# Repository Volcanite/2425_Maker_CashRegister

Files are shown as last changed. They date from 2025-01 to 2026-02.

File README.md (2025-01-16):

# 2425_Maker_CashRegister
Caisse enregistreuse à destination de la KFET. Elle permettrai de payer ses consommations et d'en avoir une traçabilité. On aurait également la possibilité de gérer les stocks et prévenir en cas de rupture. On pourrait également modifier les prix et les consommables proposés.

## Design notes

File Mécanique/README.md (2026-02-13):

# 2425_Maker_CashRegister

    En seconde année à l'ENSEA, un projet de conception d'une caisse enregistreuse ainsi que le module de paiement a été entreprit. Ce projet répond à une problématique de trésorerie présente dans l'école. En effet, durant chaque pause à la K-FET de l'école ou durant les événements, des produits sont mis en vente. Le personnel de l'école et les étudiants sont nombreux à payer en espèce et certains aimeraient payer en carte bancaise et cela engendre deux problèmes :
     - Les staffeurs doivent faire un bilan de la caisse réguliérement pour tenir les comptes ce qui est difficile dans certaines périodes.
     - Le paiement par carte bancaire implique soit un TPE qui impose des frais soit une application de paiement associatif sécurisée (Lyf, Lydia, HelloAsso, ...) qui ne sont pas le plus pratique au quotidien. 
     
     Des solutions ont été proposés mais cela demande la participation journalière d'étudiant. 
    
        Ainsi débute le projet de la caisse enregistreuse. Globalement on attend de celle-ci qu'elle puisse prendre des commandes et encaisser. Qu'elle puisse être reliée à plusieurs terminale de paiement permettant de traiter plusieurs clients à la fois en parallèle. Elle pourrait également aider les staffeurs sur le bilan de la caisse en liquidité et en paiement par carte ainsi qu'à faire un compte rendu des stocks. Evidemment tout cela serait sur base de donnée afin de pouvoir adapter l'interface à l'association et aux événements en cours. Enfin, une interface client serait mis à disposition afin de pouvoir créditer sa carte et suivre ses dernières transactions. Tout cela étant sauvegarder sur serveur avec backups en cas de problème.

## Décomposition du projet :
    Le projet se décompose en trois grandes parties : 
    - Mécanique : Modélisation et conception de la caisse à l'aide des outils présents à l'école. [lien vers Readme partie mécanique](./)
    - Electronique : Modélisation et conception d'une carte électronique pour le terminal de paiement permettant l'assemblage de différent module.
    - Software : Programmation embarquée de la caisse et du terminal de paiement. Réalisation d'une base de donnée hébergé sur serveur. Programmation d'une interface homme machine sur la caisse et d'un site utilisateur pour les clients et staffeurs.

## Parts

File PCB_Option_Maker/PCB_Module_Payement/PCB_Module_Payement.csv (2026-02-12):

Reference | Value | Datasheet | Footprint | Qty | DNP
BZ1 | Buzzer | ~ | Buzzer_Beeper:Buzzer_12x9.5RM7.6 | 1
C1 | 10u | ~ | Capacitor_SMD:C_0805_2012Metric | 1
C2,C4,C5,C13,C17,C19,C212 | 1u | https://www.we-online.com/components/products/datasheet/885012105006.pdf,~ | Capacitor_SMD:C_0402_1005Metric,Capacitor_SMD:C_0603_1608Metric | 7
C3 | 47u | ~ | Capacitor_SMD:C_0805_2012Metric | 1
C6 | 4u7 | ~ | Capacitor_SMD:C_0402_1005Metric | 1
C7,C10,C11,C12,C14,C16,C18,C211 | 100n | ~ | Capacitor_SMD:C_0402_1005Metric | 8
D1 | LED Blue | https://www.we-online.com/components/products/datasheet/150060RS55040.pdf | LED_SMD:LED_0603_1608Metric | 1
D2 | LED Amber | https://www.we-online.com/components/products/datasheet/150060AS55040.pdf | LED_SMD:LED_0603_1608Metric | 1
D3 | LED Yellow | https://www.we-online.com/components/products/datasheet/150060YS55040.pdf | LED_SMD:LED_0603_1608Metric | 1
D4 | LED_Blue | https://www.we-online.com/components/products/datasheet/150060BS55040.pdf | LED_SMD:LED_0603_1608Metric | 1
D5 | LED_Green | ~ | LED_SMD:LED_0603_1608Metric | 1
H1,H2,H3,H4 | MountingHole_Pad | ~ | MountingHole:MountingHole_2.7mm_M2.5_Pad | 4
J1 | Conn_02x07_Odd_Even | ~ | Connector_PinHeader_2.54mm:PinHeader_2x07_P2.54mm_Horizontal | 1
J3,J5 | Conn_01x08 | ~ | Connector_PinHeader_2.54mm:PinHeader_1x08_P2.54mm_Horizontal | 2
J4 | Conn_01x06 | ~ | Connector_PinHeader_2.54mm:PinHeader_1x06_P2.54mm_Horizontal | 1
J6 | Conn_01x04 | ~ | Connector_PinHeader_2.54mm:PinHeader_1x04_P2.54mm_Horizontal | 1
J7 | Conn_01x02 | ~ | Connector_JST:JST_XA_S02B-XASK-1_1x02_P2.50mm_Horizontal | 1
J8 | USB_C_Receptacle_USB2.0 | https://www.usb.org/sites/default/files/documents/usb_type-c.zip | Connector_USB:USB_C_Receptacle_HRO_TYPE-C-31-M-12 | 1
J9 | Conn_ST_STDC14 | https://www.st.com/content/ccc/resource/technical/document/user_manual/group1/99/49/91/b6/b2/3a/46/e5/DM00526767/files/DM00526767.pdf/jcr:content/translations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 | Connector_PinHeader_1.27mm:PinHeader_2x07_P1.27mm_Vertical_SMD | 1
J_Switch1 | Conn_01x03 | ~ | Connector_JST:JST_XA_S03B-XASK-1_1x03_P2.50mm_Horizontal | 1
L201 | 39n | ~ | Inductor_SMD:L_0805_2012Metric | 1
Q2 | MMBT2222A | https://assets.nexperia.com/documents/data-sheet/MMBT2222A.pdf | Package_TO_SOT_SMD:SOT-23 | 1
R1,R17,R19,R23 | 10K | ~ | Resistor_SMD:R_0402_1005Metric | 4
R2 | 168K | ~ | Resistor_SMD:R_0402_1005Metric | 1
R3 | 5k6 | ~ | Resistor_SMD:R_0402_1005Metric | 1
R4 | 49k9 | ~ | Resistor_SMD:R_0402_1005Metric | 1
R5,R6,R7,R9 | 10k | ~ | Resistor_SMD:R_0402_1005Metric | 4
R8 | 1K | ~ | Resistor_SMD:R_0402_1005Metric | 1
R10 | 68K | ~ | Resistor_SMD:R_0402_1005Metric | 1
R11,R12 | 5.1K | ~ | Resistor_SMD:R_0402_1005Metric | 2
R13,R14,R15 | 1k7 | ~ | Resistor_SMD:R_0402_1005Metric | 3
R20 | 510 | ~ | Resistor_SMD:R_0402_1005Metric | 1
R21 | R | ~ | Resistor_SMD:R_0402_1005Metric | 1
SW1,SW2,SW3 | SW_Push | ~ | Button_Switch_SMD:SW_Push_1P1T_NO_CK_KSC6xxJ | 3
U1,U5 | FSV330AF | https://www.farnell.com/datasheets/2572325.pdf | Schuttky:DO-214AD_ONS | 2
U2 | STM32G431CBUx | https://www.st.com/resource/en/datasheet/stm32g431cb.pdf | Package_DFN_QFN:QFN-48-1EP_7x7mm_P0.5mm_EP5.6x5.6mm | 1
U3 | 171013801 | https://www.we-online.com/en/components/products/datasheet/171013801.pdf | Wurth_regulator_171013801:Wurth_171013801 | 1
U4 | BU33SD5WG-TR | BU33SD5WG-TR | footprints:SSOP5_ROM | 1
U6 | USBLC6-2SC6 | https://www.st.com/resource/en/datasheet/usblc6-2.pdf | Package_TO_SOT_SMD:SOT-23-6 | 1

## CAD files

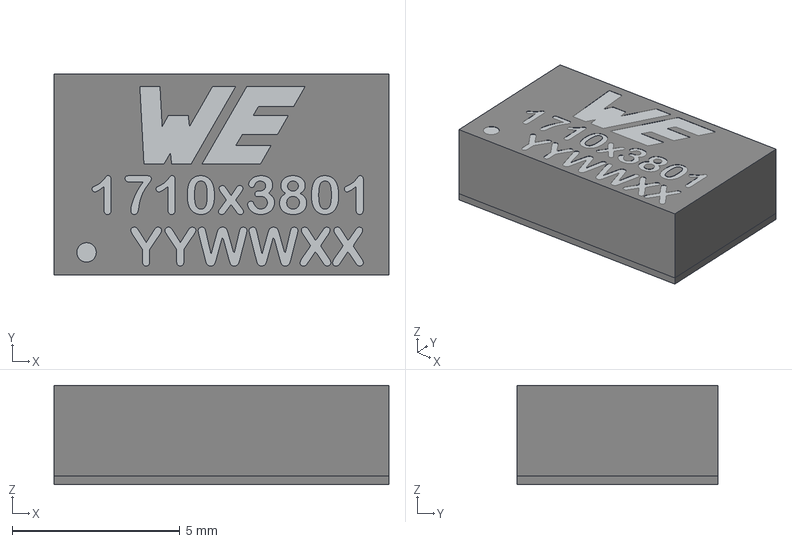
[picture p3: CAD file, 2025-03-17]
PCB_Option_Maker/PCB_Module_Payement/Wurth_171013801.stp
10.0 x 6.00 x 2.97 mm
Base
Pads

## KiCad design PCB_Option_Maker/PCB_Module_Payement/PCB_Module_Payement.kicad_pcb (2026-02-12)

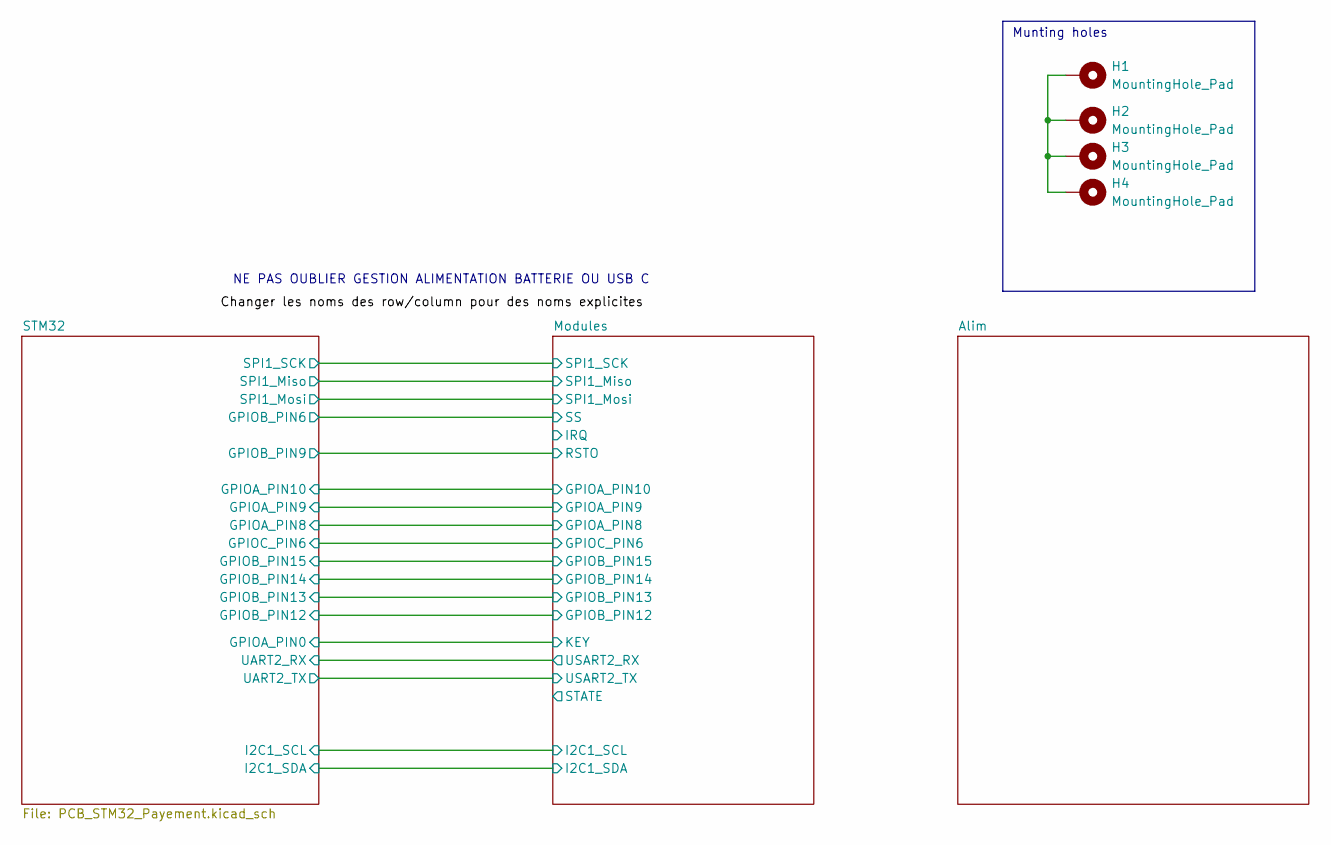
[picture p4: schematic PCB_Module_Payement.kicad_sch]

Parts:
H1, H2, H3, H4: MountingHole_Pad; MountingHole_2.7mm_M2.5_Pad

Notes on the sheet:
Munting holes
NE PAS OUBLIER GESTION ALIMENTATION BATTERIE OU USB C

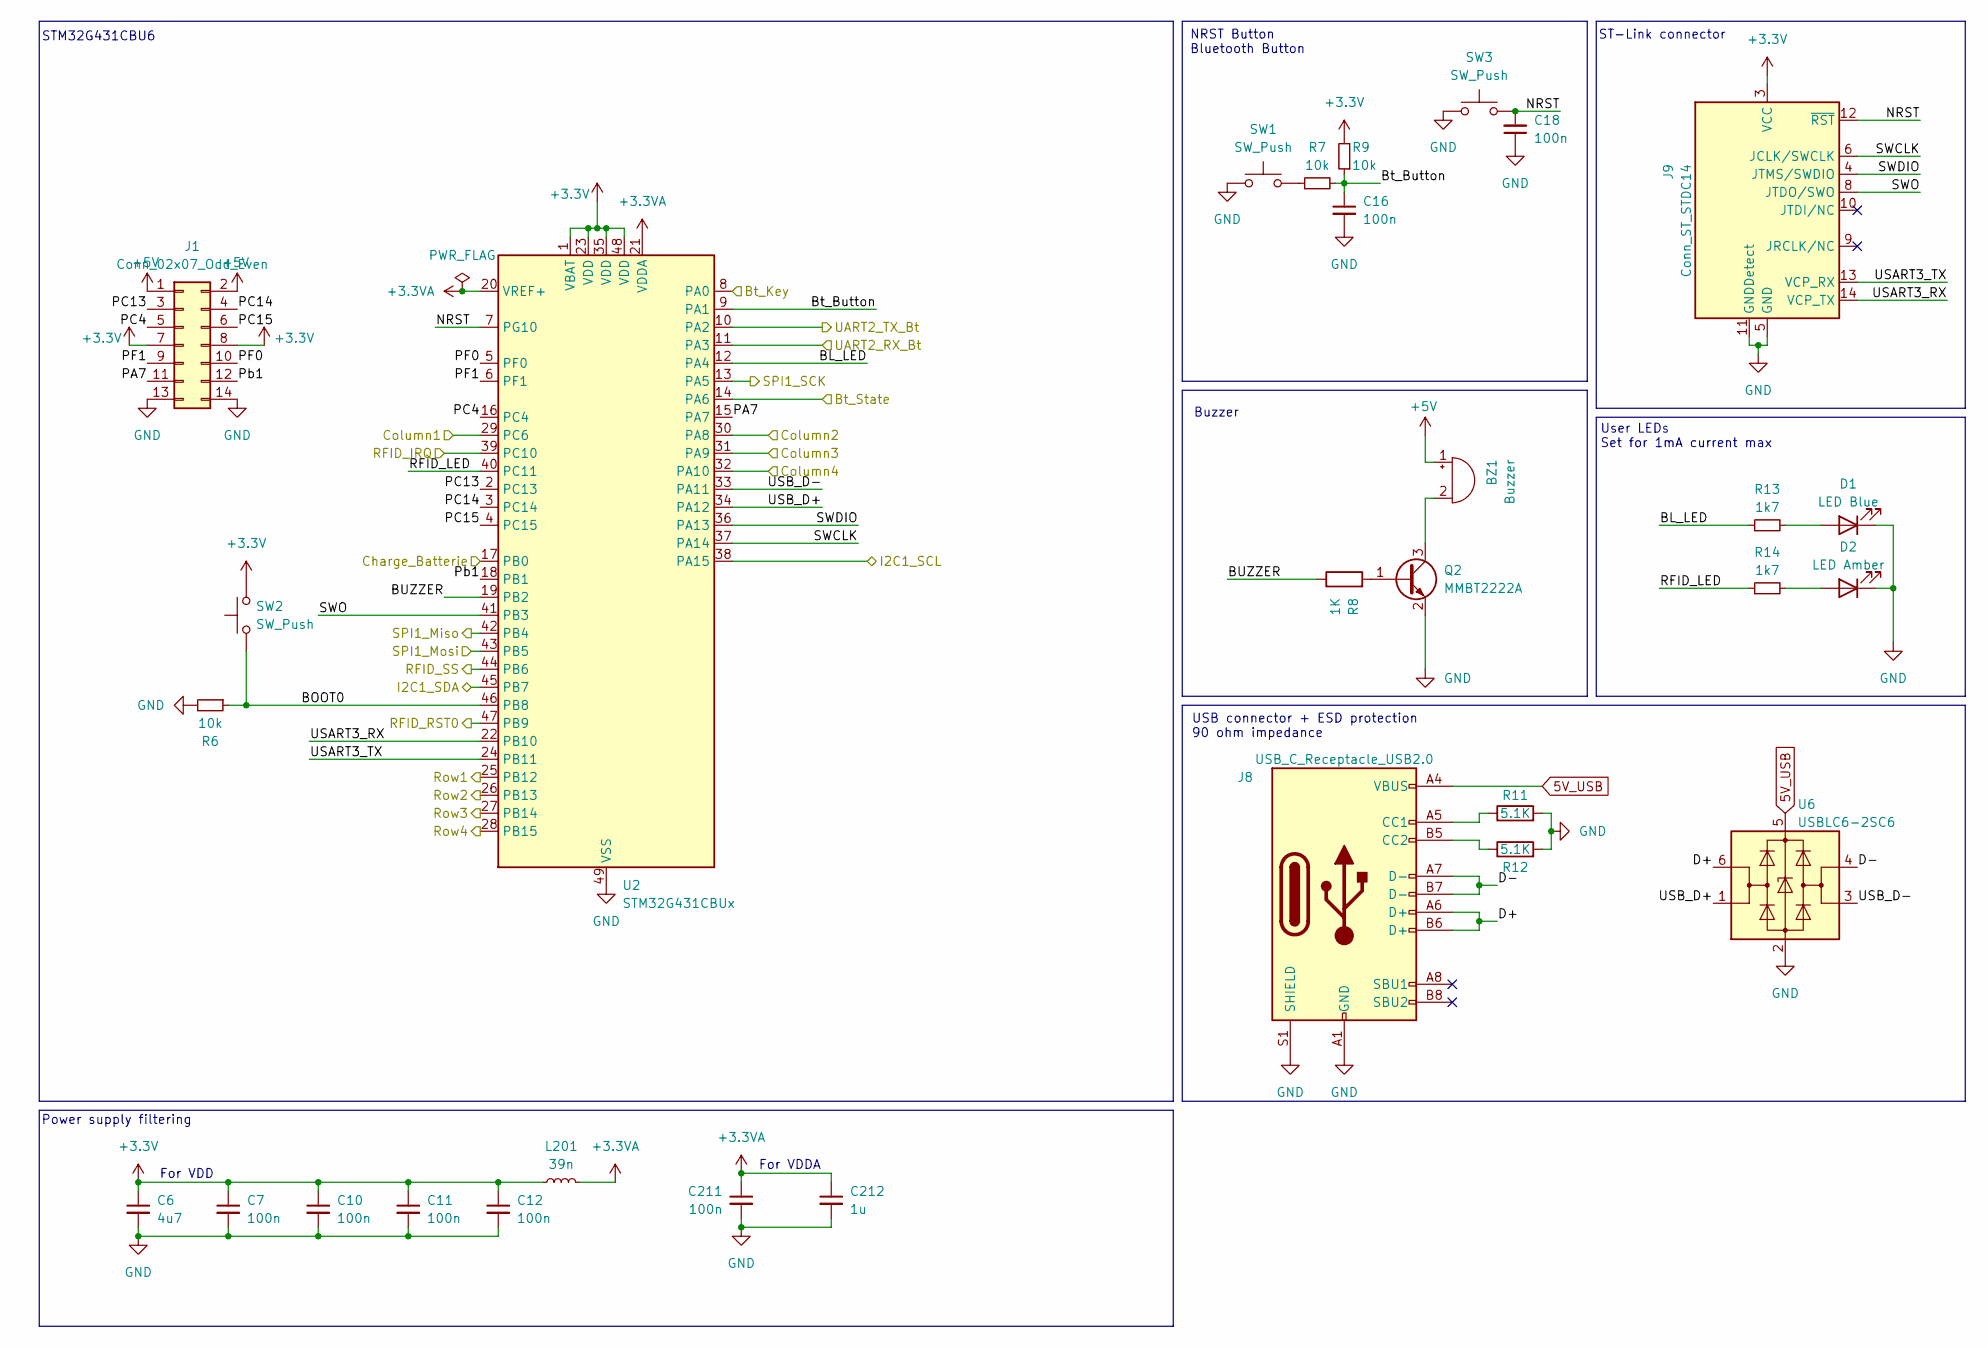
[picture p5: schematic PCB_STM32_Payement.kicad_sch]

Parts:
BZ1: Buzzer; Buzzer_12x9.5RM7.6
C6: 4u7; C_0402_1005Metric
C7, C10, C11, C12, C16, C18, C211: 100n; C_0402_1005Metric
C212: 1u; C_0603_1608Metric; MPN 885012105006
D1: LED Blue; LED_0603_1608Metric; MPN 150060RS55040
D2: LED Amber; LED_0603_1608Metric; MPN 150060AS55040
J1: Conn_02x07_Odd_Even; PinHeader_2x07_P2.54mm_Horizontal
J8: USB_C_Receptacle_USB2.0; USB_C_Receptacle_HRO_TYPE-C-31-M-12
J9: Conn_ST_STDC14; PinHeader_2x07_P1.27mm_Vertical_SMD
L201: 39n; L_0805_2012Metric
Q2: MMBT2222A; SOT-23
R6, R7, R9: 10k; R_0402_1005Metric
R8: 1K; R_0402_1005Metric
R11, R12: 5.1K; R_0402_1005Metric
R13, R14: 1k7; R_0402_1005Metric
SW1, SW2, SW3: SW_Push; SW_Push_1P1T_NO_CK_KSC6xxJ
U2: STM32G431CBUx; QFN-48-1EP_7x7mm_P0.5mm_EP5.6x5.6mm
U6: USBLC6-2SC6; SOT-23-6

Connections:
5V_USB: J8.A4 (VBUS), J8.A9 (VBUS), J8.B4 (VBUS), J8.B9 (VBUS), U6.5 (VBUS); also elsewhere on the board
+3.3V: C6.1, C7.1, C10.1, C11.1, C12.1, J1.7, J1.8, J9.3 (VCC), L201.1, R9.2, SW2.2, U2.1 (VBAT), U2.23 (VDD), U2.35 (VDD), U2.48 (VDD); also elsewhere on the board
+3.3VA: C211.1, C212.1, L201.2, U2.20 (VREF+), U2.21 (VDDA)
+5V: BZ1.1 (+), J1.1, J1.2; also elsewhere on the board
/Alim/Charge_Batterie: U2.17 (PB0); also elsewhere on the board
/Modules/Bt_RXD: U2.10 (PA2); also elsewhere on the board
/Modules/Bt_TXD: U2.11 (PA3); also elsewhere on the board
/Modules/Culomn1: U2.29 (PC6); also elsewhere on the board
/Modules/Culomn2: U2.30 (PA8); also elsewhere on the board
/Modules/Culomn3: U2.31 (PA9); also elsewhere on the board
/Modules/Culomn4: U2.32 (PA10); also elsewhere on the board
/Modules/I2C1_SCL: U2.45 (PB7); also elsewhere on the board
/Modules/I2C1_SDA: U2.38 (PA15); also elsewhere on the board
/Modules/IRQ: U2.39 (PC10); also elsewhere on the board
/Modules/KEY: U2.8 (PA0); also elsewhere on the board
/Modules/R0W1: U2.25 (PB12); also elsewhere on the board
/Modules/ROW2: U2.26 (PB13); also elsewhere on the board
/Modules/ROW3: U2.27 (PB14); also elsewhere on the board
/Modules/ROW4: U2.28 (PB15); also elsewhere on the board
/Modules/RSTO: U2.47 (PB9); also elsewhere on the board
/Modules/SPI1_Miso: U2.42 (PB4); also elsewhere on the board
/Modules/SPI1_Mosi: U2.43 (PB5); also elsewhere on the board
/Modules/SPI1_SCK: U2.13 (PA5); also elsewhere on the board
/Modules/SS: U2.44 (PB6); also elsewhere on the board
/Modules/STATE: U2.14 (PA6); also elsewhere on the board
/STM32/BL_LED: R13.1, U2.12 (PA4)
/STM32/BOOT0: R6.1, SW2.1, U2.46 (PB8)
/STM32/BUZZER: R8.1, U2.19 (PB2)
/STM32/Bt_Button: C16.1, R7.2, R9.1, U2.9 (PA1)
/STM32/D+: J8.A6 (D+), J8.B6 (D+), U6.6 (I/O1)
/STM32/D-: J8.A7 (D-), J8.B7 (D-), U6.4 (I/O2)
/STM32/NRST: C18.2, J9.12 (~RST), SW3.2, U2.7 (PG10)
/STM32/PA7: J1.11, U2.15 (PA7)
/STM32/PC4: J1.5, U2.16 (PC4)
/STM32/PC13: J1.3, U2.2 (PC13)
/STM32/PC14: J1.4, U2.3 (PC14)
/STM32/PC15: J1.6, U2.4 (PC15)
/STM32/PF0: J1.10, U2.5 (PF0)
/STM32/PF1: J1.9, U2.6 (PF1)
/STM32/Pb1: J1.12, U2.18 (PB1)
/STM32/RFID_LED: R14.1, U2.40 (PC11)
/STM32/SWCLK: J9.6 (JCLK/SWCLK), U2.37 (PA14)
/STM32/SWDIO: J9.4 (JTMS/SWDIO), U2.36 (PA13)
/STM32/SWO: J9.8 (JTDO/SWO), U2.41 (PB3)
/STM32/USART3_RX: J9.14 (VCP_TX), U2.22 (PB10)
/STM32/USART3_TX: J9.13 (VCP_RX), U2.24 (PB11)
/STM32/USB_D+: U2.34 (PA12), U6.1 (I/O1)
/STM32/USB_D-: U2.33 (PA11), U6.3 (I/O2)
unnamed: BZ1.2 (-), Q2.3 (C)
unnamed: D1.2 (A), R13.2
unnamed: D2.2 (A), R14.2
unnamed: J8.A5 (CC1), R11.1
unnamed: J8.B5 (CC2), R12.1
unnamed: Q2.1 (B), R8.2
unnamed: R7.1, SW1.2

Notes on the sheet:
ST-Link connector
User LEDs Set for 1mA current max
NRST Button Bluetooth Button
For VDDA
For VDD
Power supply filtering
Buzzer
USB connector + ESD protection 90 ohm impedance
STM32G431CBU6

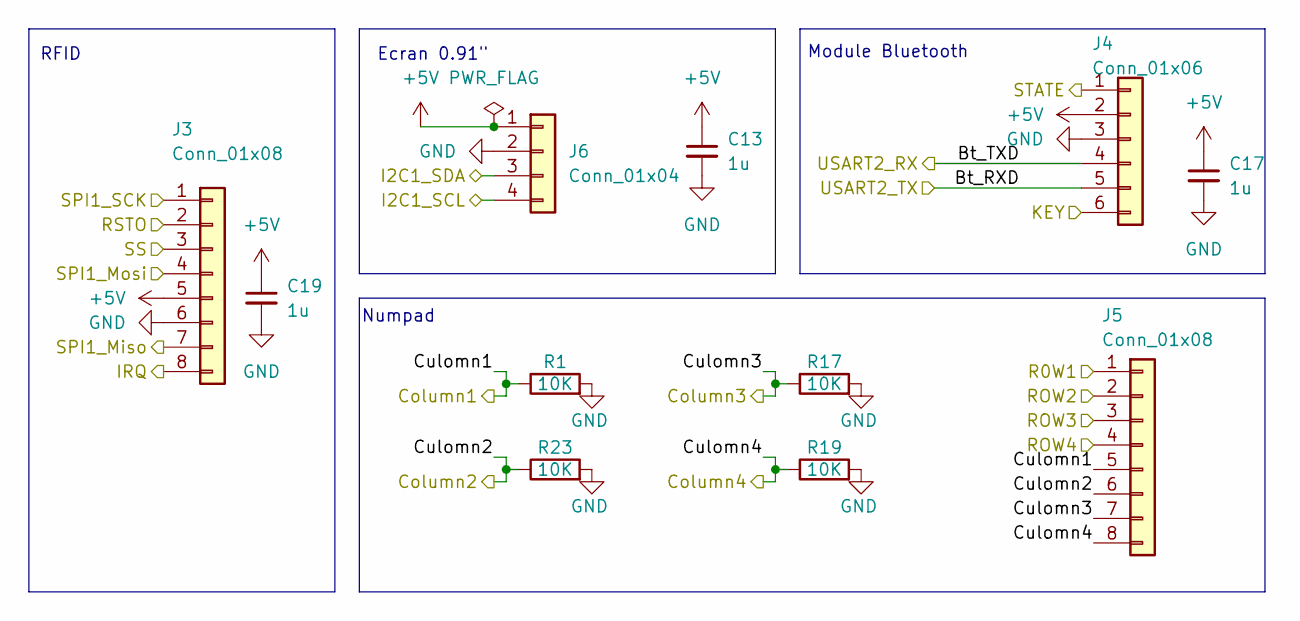
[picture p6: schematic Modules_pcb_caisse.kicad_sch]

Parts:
C13, C17, C19: 1u; C_0402_1005Metric
J3, J5: Conn_01x08; PinHeader_1x08_P2.54mm_Horizontal
J4: Conn_01x06; PinHeader_1x06_P2.54mm_Horizontal
J6: Conn_01x04; PinHeader_1x04_P2.54mm_Horizontal
R1, R17, R19, R23: 10K; R_0402_1005Metric

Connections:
+5V: C13.1, C17.1, C19.1, J3.5, J4.2, J6.1; also elsewhere on the board
/Modules/Bt_RXD: J4.5; also elsewhere on the board
/Modules/Bt_TXD: J4.4; also elsewhere on the board
/Modules/Culomn1: J5.5, R1.1; also elsewhere on the board
/Modules/Culomn2: J5.6, R23.1; also elsewhere on the board
/Modules/Culomn3: J5.7, R17.1; also elsewhere on the board
/Modules/Culomn4: J5.8, R19.1; also elsewhere on the board
/Modules/I2C1_SCL: J6.4; also elsewhere on the board
/Modules/I2C1_SDA: J6.3; also elsewhere on the board
/Modules/IRQ: J3.8; also elsewhere on the board
/Modules/KEY: J4.6; also elsewhere on the board
/Modules/R0W1: J5.1; also elsewhere on the board
/Modules/ROW2: J5.2; also elsewhere on the board
/Modules/ROW3: J5.3; also elsewhere on the board
/Modules/ROW4: J5.4; also elsewhere on the board
/Modules/RSTO: J3.2; also elsewhere on the board
/Modules/SPI1_Miso: J3.7; also elsewhere on the board
/Modules/SPI1_Mosi: J3.4; also elsewhere on the board
/Modules/SPI1_SCK: J3.1; also elsewhere on the board
/Modules/SS: J3.3; also elsewhere on the board
/Modules/STATE: J4.1; also elsewhere on the board

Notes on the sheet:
Numpad
RFID
Module Bluetooth
Ecran 0.91"

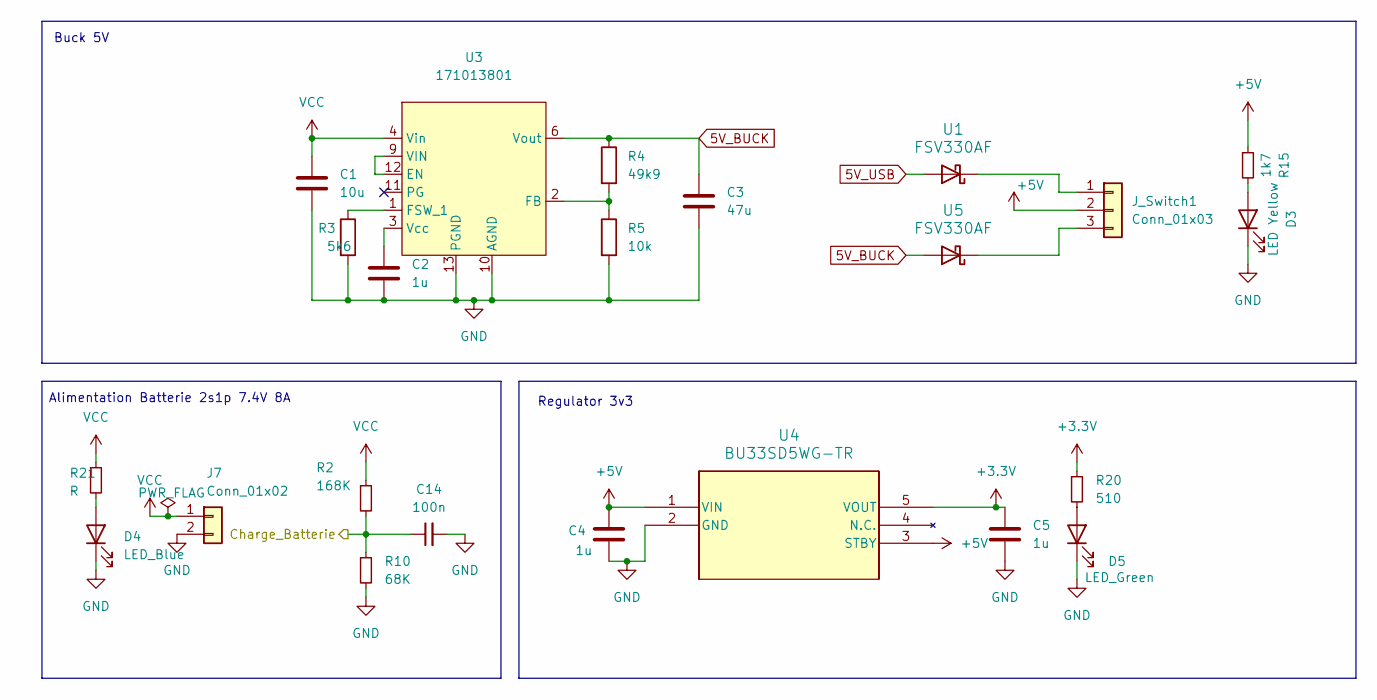
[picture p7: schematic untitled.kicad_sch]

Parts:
C1: 10u; C_0805_2012Metric
C2, C4, C5: 1u; C_0402_1005Metric
C3: 47u; C_0805_2012Metric
C14: 100n; C_0402_1005Metric
D3: LED Yellow; LED_0603_1608Metric; MPN 150060YS55040
D4: LED_Blue; LED_0603_1608Metric
D5: LED_Green; LED_0603_1608Metric
J7: Conn_01x02; JST_XA_S02B-XASK-1_1x02_P2.50mm_Horizontal
J_Switch1: Conn_01x03; JST_XA_S03B-XASK-1_1x03_P2.50mm_Horizontal
R2: 168K; R_0402_1005Metric
R3: 5k6; R_0402_1005Metric
R4: 49k9; R_0402_1005Metric
R5: 10k; R_0402_1005Metric
R10: 68K; R_0402_1005Metric
R15: 1k7; R_0402_1005Metric
R20: 510; R_0402_1005Metric
R21: R; R_0402_1005Metric
U1, U5: FSV330AF; DO-214AD_ONS; MPN FSV330AF
U3: 171013801; Wurth_171013801; MPN 171013801
U4: BU33SD5WG-TR; SSOP5_ROM

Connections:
5V_BUCK: C3.1, R4.1, U3.6 (Vout), U3.7 (Vout), U5.2 (A)
5V_USB: U1.2 (A); also elsewhere on the board
+3.3V: C5.2, R20.1, U4.5 (VOUT); also elsewhere on the board
+5V: C4.1, J_Switch1.2, R15.1, U4.1 (VIN), U4.3 (STBY); also elsewhere on the board
/Alim/Charge_Batterie: C14.1, R2.2, R10.1; also elsewhere on the board
unnamed: D3.2 (A), R15.2
unnamed: D4.2 (A), R21.2
unnamed: D5.2 (A), R20.2
unnamed: J_Switch1.1, U1.1 (K)
unnamed: J_Switch1.3, U5.1 (K)
unnamed: U3.9 (VIN), U3.12 (EN)
unnamed: R4.2, R5.1, U3.2 (FB)
unnamed: R3.1, U3.1 (FSW_1)
unnamed: C2.1, U3.3 (Vcc)
VCC: C1.1, J7.1, R2.1, R21.1, U3.4 (Vin), U3.5 (Vin)

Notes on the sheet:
Alimentation Batterie 2s1p 7.4V 8A
Regulator 3v3
Buck 5V

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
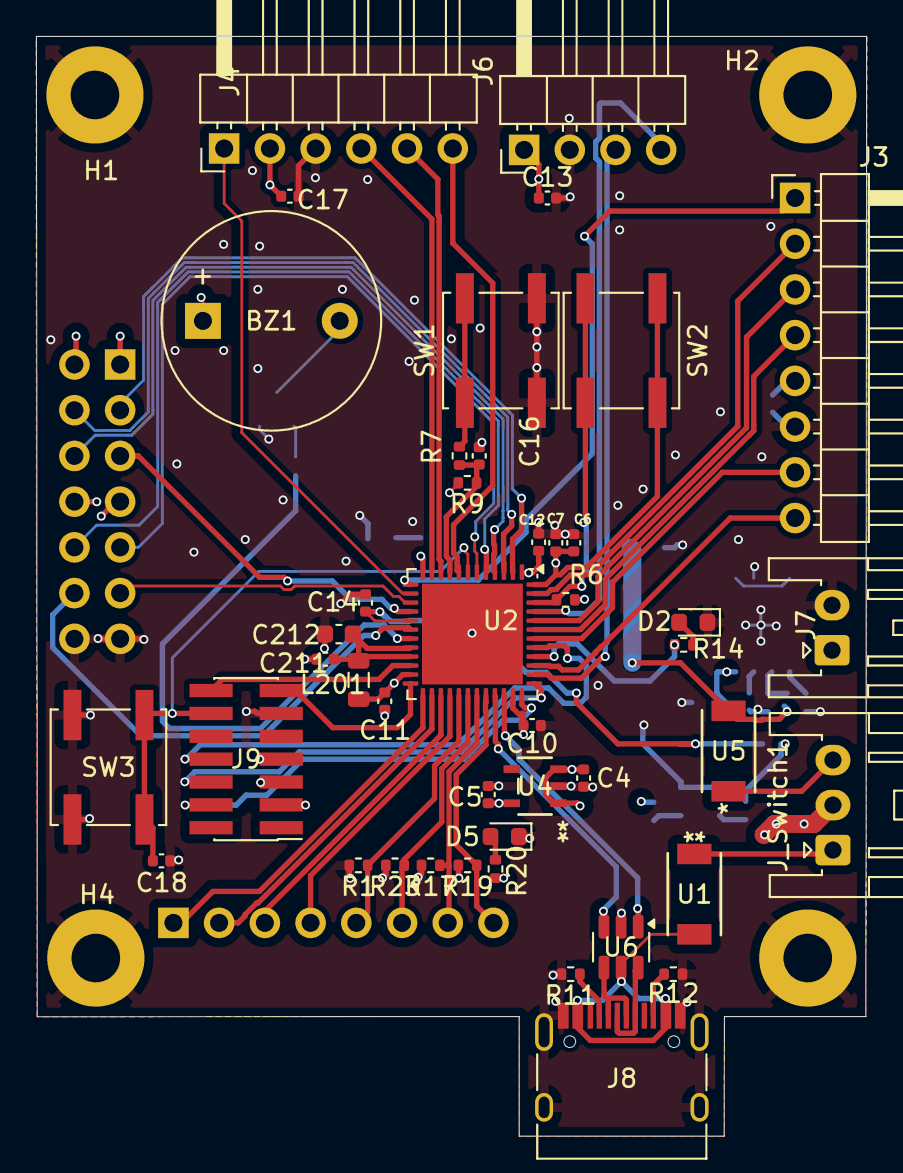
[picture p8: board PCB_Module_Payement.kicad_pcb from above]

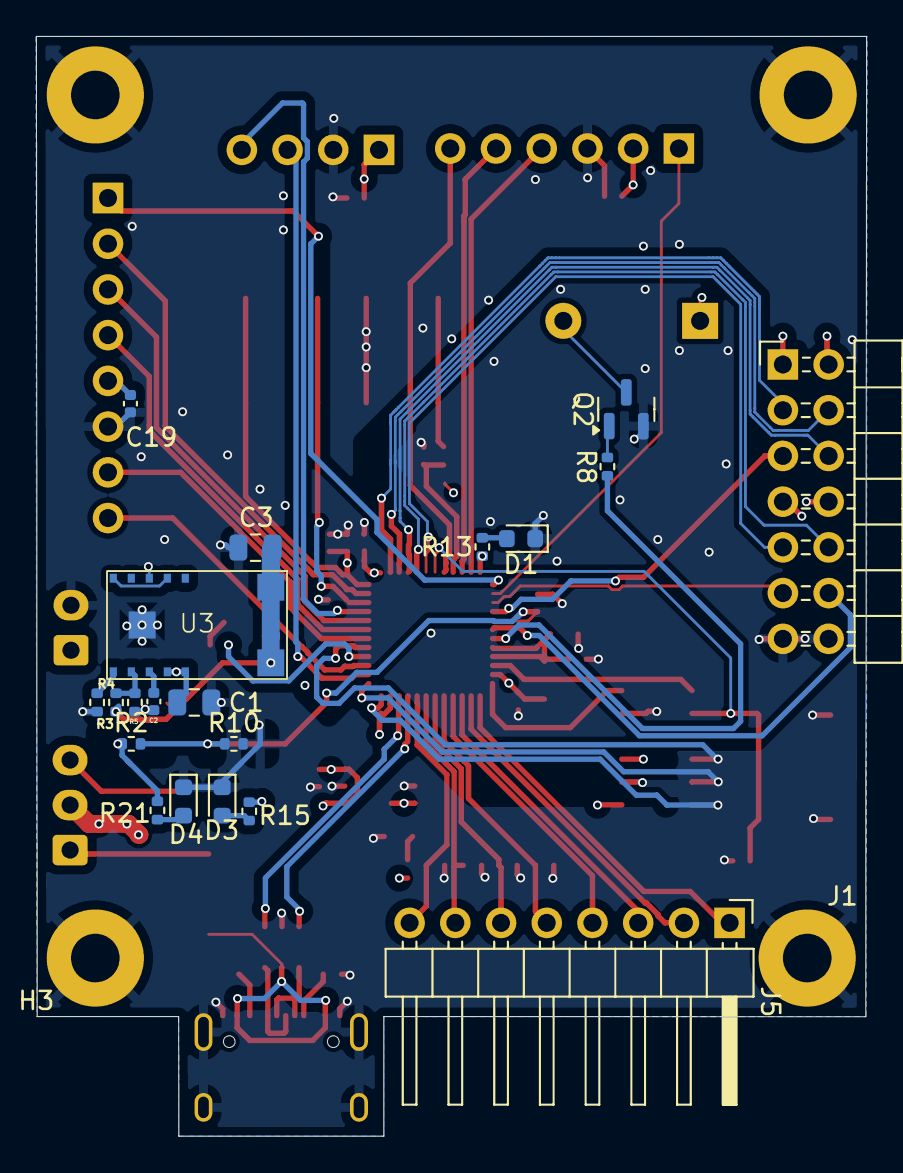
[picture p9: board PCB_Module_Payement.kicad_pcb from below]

Board: 4 copper layers, 46.1 x 61.1 mm, 68 parts (20 on the bottom side), 67 nets.

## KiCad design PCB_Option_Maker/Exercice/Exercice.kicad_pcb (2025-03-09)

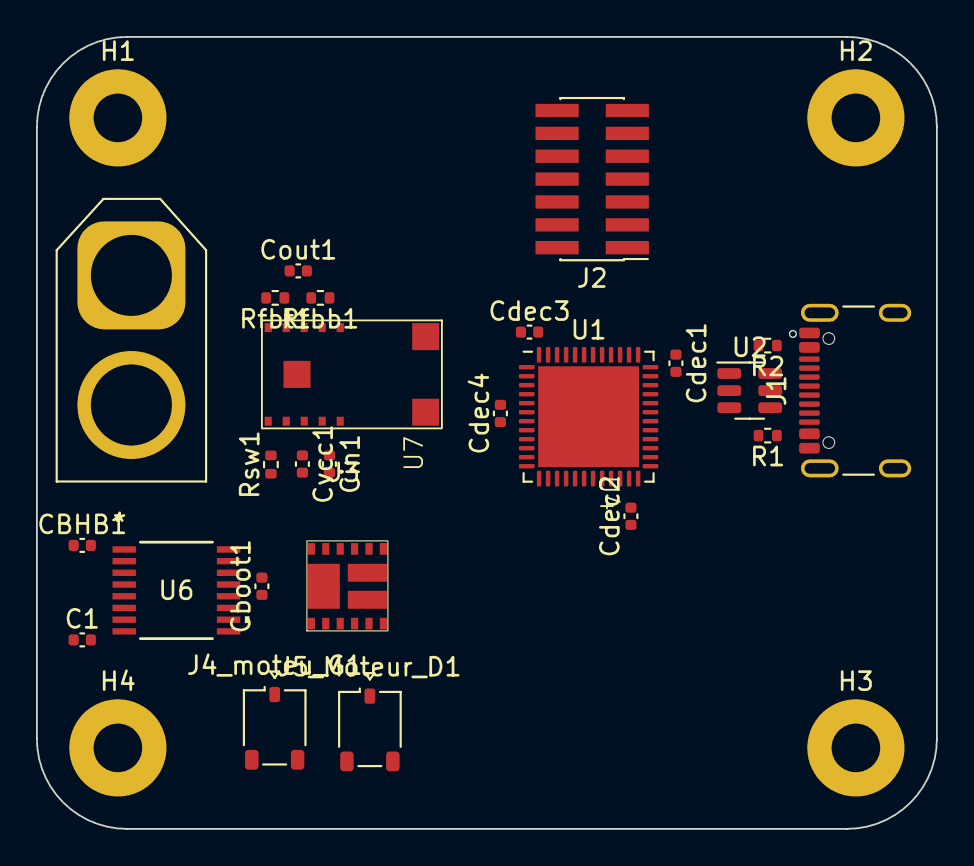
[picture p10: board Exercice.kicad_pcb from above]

Board: 4 copper layers, 50.0 x 44.0 mm, 29 parts (0 on the bottom side), 28 nets, no tracks yet.

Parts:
C1: 0.2u; C_0402_1005Metric
CBHB1: 0.2u; C_0402_1005Metric
Cboot1: 2u; C_0402_1005Metric
Cdec1: 4u7; C_0402_1005Metric
Cdec2, Cdec3, Cdec4: 100n; C_0402_1005Metric
Cin1: 10u; C_0402_1005Metric
Cout1: 47u; C_0402_1005Metric
Cvcc1: 1u; C_0402_1005Metric
H1, H2, H3, H4: MountingHole_Pad; MountingHole_2.7mm_M2.5_Pad
J1: USB_C_Receptacle_USB2.0_16P; USB_C_Receptacle_GCT_USB4105-xx-A_16P_TopMnt_Horizontal
J2: Conn_02x07_Odd_Even; PinHeader_2x07_P1.27mm_Vertical_SMD
J3: Conn_01x02; AMASS_XT60-F_1x02_P7.20mm_Vertical
J4_moteu_G1, J5_Moteur_D1: Conn_01x01; JST_ACH_BM01B-ACHSS-A-GAN-ETF_1x01-1MP_P1.20mm_Vertical
R1, R2: 5.1K; R_0402_1005Metric
Rfbb1: 137K; R_0402_1005Metric
Rfbt1: 402K; R_0402_1005Metric
Rsw1: 5.6K; R_0402_1005Metric
U1: STM32G431CBUx; QFN-48-1EP_7x7mm_P0.5mm_EP5.6x5.6mm
U2: USBLC6-2SC6; SOT-23-6
U4: Wurth_171013801
U6: MIC4606-2YTS-TR; TSSOP16_TS_MCH_MIS
U7: NMOS_FDMQ86530L

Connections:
/AHO: U6.9 (AHO), U7.12 (G4)
/ALO: U6.11 (ALO), U7.9 (G3)
/APWM: U1.13 (PA5), U6.6 (APWM)
/BHO: U6.16 (BHO), U7.1 (G1)
/BLO: U6.14 (BLO), U7.4 (G2)
/BPWM: U1.14 (PA6), U6.3 (BPWM)
/D+: J1.A6 (D+), J1.B6 (D+), U2.6 (I/O1)
/D-: J1.A7 (D-), J1.B7 (D-), U2.4 (I/O2)
/GND: Cin1.2, Cout1.2, Cvcc1.2, Rfbb1.1, Rsw1.1, U4.10 (AGND), U4.13 (PGND)
/NRST: Cdec4.1, J2.12, U1.7 (PG10)
/SWDCK: J2.6, U1.37 (PA14)
/SWDIO: J2.4, U1.36 (PA13)
/USB_DM: U1.33 (PA11), U2.3 (I/O2)
/USB_DP: U1.34 (PA12), U2.1 (I/O1)
/Usart2_Rx: J2.13, U1.11 (PA3)
/Usart2_Tx: J2.14, U1.10 (PA2)
/V_USB: J1.A4 (VBUS), J1.A9 (VBUS), J1.B4 (VBUS), J1.B9 (VBUS), U2.5 (VBUS)
/Vout_3V3: Cdec1.2, Cdec2.2, Cdec3.2, Cout1.1, J2.3, Rfbt1.2, U1.1 (VBAT), U1.20 (VREF+), U1.21 (VDDA), U1.23 (VDD), U1.35 (VDD), U1.48 (VDD), U4.6 (Vout), U4.7 (Vout)
ISO_GND: C1.1, CBHB1.1, Cboot1.2, Cdec1.1, Cdec2.1, Cdec3.1, Cdec4.2, H1.1, H2.1, H3.1, H4.1, J1.A1 (GND), J1.A12 (GND), J1.B1 (GND), J1.B12 (GND), J1.S1 (SHIELD), J2.5, J2.7, J2.11, J3.1, J4_moteu_G1.1, J5_Moteur_D1.1, R1.2, R2.2, U1.49 (VSS), U2.2 (GND), U6.10 (AHS), U6.15 (BHS), U7.3 (S1/D2), U7.5 (S2), U7.6 (S2), U7.7 (S3), U7.8 (S3), U7.10 (D3/S4)
unnamed: J1.A5 (CC1), R1.1
unnamed: J1.B5 (CC2), R2.1
unnamed: U4.9 (VIN), U4.12 (EN)
unnamed: Rfbb1.2, Rfbt1.1, U4.2 (FB)
unnamed: Rsw1.2, U4.1 (FSW_1)
unnamed: Cvcc1.1, U4.3 (Vcc)
unnamed: C1.2, U6.8 (AHB)
unnamed: CBHB1.2, U6.1 (BHB)
Vin_15V: Cboot1.1, Cin1.1, J3.2, U4.4 (Vin), U4.5 (Vin), U6.2 (EN), U6.12 (VDD), U7.2 (D1/D4), U7.11 (D1/D4)

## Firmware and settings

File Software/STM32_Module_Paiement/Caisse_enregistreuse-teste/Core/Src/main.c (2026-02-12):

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
/* Includes ------------------------------------------------------------------*/
#include "main.h"
#include "adc.h"
#include "i2c.h"
#include "tim.h"
#include "usart.h"
#include "gpio.h"

/* USER CODE BEGIN Includes */
#include "ssd1306.h"
#include "Screen.h"
/* USER CODE END Includes */


void SystemClock_Config(void);
/* USER CODE BEGIN 0 */
#ifdef __GNUC__
#define PUTCHAR_PROTOTYPE int __io_putchar(int ch)
#else
#define PUTCHAR_PROTOYPE int fputc(int ch, FILE *f)
#endif

PUTCHAR_PROTOTYPE
{
	HAL_UART_Transmit(&huart2, (uint8_t *)&ch, 1, HAL_MAX_DELAY);
	return ch;
}


/* USER CODE END 0 */

/**
 * @brief  The application entry point.
 * @retval int
 */
int main(void)
{

	/* MCU Configuration--------------------------------------------------------*/

	/* Reset of all peripherals, Initializes the Flash interface and the Systick. */
	HAL_Init();

	/* Configure the system clock */
	SystemClock_Config();

	/* Initialize all configured peripherals */
	MX_GPIO_Init();
	MX_USART2_UART_Init();
	MX_TIM2_Init();
	MX_UART5_Init();
	MX_I2C1_Init();
	MX_I2C2_Init();
	MX_ADC1_Init();
	/* USER CODE BEGIN 2 */
	printf("Hello!\r\n");
	RFID_init();
	RFID_Get_UID_Card();
	Initialisation();
	HAL_Delay(1500);
	Default_Use();
	/*
	RFID_init();
	RFID_Get_UID_Card();
	RFID_Get_Block_Information();*/ // RFID lire carte
	/* USER CODE END 2 */

	/* Infinite loop */
	/* USER CODE BEGIN WHILE */
	while (1)
	{

		/* USER CODE END WHILE */

		/* USER CODE BEGIN 3 */



	}


	/* USER CODE END 3 */
}

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
/* USER CODE BEGIN 4 */
void HAL_GPIO_EXTI_Callback(uint16_t GPIO_Pin){
	// Déterminer quelle colonne a déclenché

}

void HAL_UART_RxCpltCallback(UART_HandleTypeDef *huart) {
	/*if (huart->Instance == UART5) {
		HAL_GPIO_TogglePin(green_GPIO_Port, green_Pin);  // Toggle la LED pour indiquer la réception

		// Ajouter un caractère de fin pour afficher les données
		buffer[sizeof(buffer) - 1] = '\0';

		// Afficher les données reçues
		printf("Reçu : %s\n", buffer);

		// Écho des données reçues
		HAL_UART_Transmit(&huart5, buffer, strlen((char*)buffer), HAL_MAX_DELAY);

		// Réactiver la réception
		HAL_UART_Receive_IT(&huart5, buffer, sizeof(buffer));
	}*/
}
/* USER CODE END 4 */
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


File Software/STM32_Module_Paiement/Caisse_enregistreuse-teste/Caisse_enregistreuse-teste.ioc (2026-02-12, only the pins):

Mcu.UserName=STM32L476RGTx
PA0.Signal=S_TIM2_CH1
PA10.GPIO_Label=Col4
PA10.Signal=GPIO_Output
PA2.GPIO_Label=USART_TX
PA2.Signal=USART2_TX
PA3.GPIO_Label=USART_RX
PA3.Signal=USART2_RX
PA5.GPIO_Label=green
PA5.Signal=GPIO_Output
PA8.GPIO_Label=Row3
PA8.Signal=GPIO_Input
PA9.GPIO_Label=Row2
PA9.Signal=GPIO_Input
PB0.GPIO_Label=PN532_RST
PB0.Signal=GPIO_Output
PB1.GPIO_Label=PN532_REQ
PB1.Signal=GPIO_Output
PB10.GPIO_Label=Row4
PB10.Signal=GPIO_Input
PB13.Signal=I2C2_SCL
PB14.Signal=I2C2_SDA
PB5.GPIO_Label=Col2
PB5.Signal=GPIO_Output
PB6.Signal=I2C1_SCL
PB7.GPIO_Label=RESET
PB7.Signal=GPIO_Output
PB9.Signal=I2C1_SDA
PC1.Signal=ADCx_IN2
PC10.GPIO_Label=IRQ
PC10.Signal=GPIO_Input
PC12.GPIO_Label=TX_BT_RX
PC12.Signal=UART5_TX
PC13.GPIO_Label=B1 [Blue PushButton]
PC13.Signal=GPXTI13
PC7.GPIO_Label=Row1
PC7.Signal=GPIO_Input
PD2.GPIO_Label=RX_BT_TX
PD2.Signal=UART5_RX

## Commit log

2025-03-17 Create PCB_CashRegister
2025-03-17 add pcb
    [Modules_pcb_caisse.kicad_sch, PCB_Module_Payement.kicad_pcb, PCB_Module_Payement.kicad_sch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]
2025-03-17 update schematci
    [Modules_pcb_caisse.kicad_sch, PCB_Module_Payement.kicad_sch, PCB_STM32_Payement.kicad_sch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]
2025-03-20 pcb update
    [Modules_pcb_caisse.kicad_sch, PCB_Module_Payement.kicad_pcb, PCB_Module_Payement.kicad_sch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]
2025-03-22 update pcb
    [PCB_Module_Payement.kicad_pcb, untitled.kicad_sch]
2025-03-31 stm32 test rfid
    [PCB_Module_Payement.kicad_pcb]
2026-02-12 Fichier indépendant bluetooth, rfid par I2C, écran
    [PCB_Module_Payement.csv, PCB_Module_Payement.kicad_pcb]
2026-02-12 Fichier indépendant bluetooth, rfid par I2C, écran (1)
2026-02-12 Fichier indépendant bluetooth, rfid par I2C, écran (2)

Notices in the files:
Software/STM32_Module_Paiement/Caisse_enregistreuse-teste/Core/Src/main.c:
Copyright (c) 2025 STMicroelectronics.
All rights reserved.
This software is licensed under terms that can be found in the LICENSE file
